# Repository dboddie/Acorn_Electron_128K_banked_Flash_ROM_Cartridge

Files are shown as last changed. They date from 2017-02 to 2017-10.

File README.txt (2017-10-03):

Introduction
------------

This repository provides schematic and circuit layout files for use with KiCad
describing a 128K Flash ROM cartridge suitable for use with the Acorn Electron
microcomputer's Plus 1 expansion unit. It is based on Paul Boddie's original
prototyping breakout cartridge.

The following resources are provided:

AcornElectronCartridge.kicad_pcb    The circuit board layout

AcornElectronCartridge.net          The netlist, generated from the schematic
                                    and distributed here for convenience

AcornElectronCartridge.pro          The KiCad project file

AcornElectronCartridge.sch          The circuit schematic providing the
                                    relationships between components

AcornElectron.lib                   Acorn Electron component library
                                    containing definitions for the edge
                                    connector (used by the schematic editor)

AcornElectron.pretty                Acorn Electron component footprint library
                                    containing definitions of the edge
                                    connector (used by the PCB editor)

BoardOutline                        Drawings defining the board outline plus
                                    descriptions of the drafting workflow and
                                    KiCad import considerations

Preparing the Schematic
-----------------------

Since the purpose of the board is merely that of routing signals, the
schematic is very simple. Connectors corresponding to the two sides of the
board edge connector are introduced, together with breakout connectors
corresponding to the exposed signals. Each edge connector pin is labelled and
a corresponding breakout connector pin is given a matching label. Thus, an
association is established between the edge connector pin and the breakout
pin.

The CvPcb tool in KiCad associates components with footprints. For convenient
prototyping, the breakout connectors are associated with headers with 0.1 inch
pin spacing (or pitch). The edge connectors are associated with specially
designed footprints for the Acorn Electron cartridge provided by the Acorn
Electron footprint component library (AcornElectron.pretty).

Preparing the Board Outline
---------------------------

In order to produce a board of the right shape (or indeed of any shape), a
board outline must first be produced. The BoardOutline directory contains
documentation of the workflow involved in applying measurements used by other
cartridges to produce a suitable drawing (cartridge_board_rear.dxf) which can
then be used in KiCad (and by subsequent production tools) to establish the
correct positions and dimensions of board features such as mounting holes and
the edge connector portion of the board.

This board outline is exported as DXF (using version 14 in Inkscape) and
imported into KiCad to provide the basis of the board itself. The outline is
imported into the Edge.Cuts layer, indicating that it shall be used to direct
cutting tools to define the shape of the board. In order to align the outline
with a grid using 0.127mm (0.05 inch) units, the origin of the outline is
positioned at (60.445mm, 127mm). More information about the calculations can
be found in the BoardOutline documentation.

Preparing the Board Layout
--------------------------

Each component must be positioned appropriately on the board for it to make
any physical sense. The edge connector footprints must be placed on each side
of the protruding portion of the board, and the breakout connector footprints
must be placed high enough up on the board to be accessible when the cartridge
is inserted into the Plus 1. Beyond this, board layout is mostly a matter of
routing tracks between connectors and avoiding board features such as mounting
holes and the board edges.

Design Rules and Production
---------------------------

The original prototyping cartridge was sent to OSHPark for production. Thus,
the design rules for OSHPark were added to the project configuration. Such
rules can be found here:

http://docs.oshpark.com/services/two-layer/
http://docs.oshpark.com/design-tools/kicad/kicad-design-rules/

Contact, Copyright and Licence Information
------------------------------------------

The author can be contacted at the following e-mail address:

david@boddie.org.uk

Copyright and licence information can be found in the docs directory - see
docs/COPYING.txt and docs/gpl-3.0.txt for more information.

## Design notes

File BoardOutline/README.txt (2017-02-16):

Files
-----

The cartridge_board_measurements.svg file was converted to the form defined by
cartridge_board.svg by removing dimension details, setting stroke widths to 0
for all objects, converting shapes to paths, performing a union operation on
the main board shape with the rectangles providing material for the edge
connector curvature (see below), then using the difference operation to remove
all cutout shapes. This should leave a single path object defining the board
minus the cutouts.

The cartridge_board_rear.svg file takes the board shape, flips it
horizontally, and converts all curves to lines by adding more points (three
times appears sufficient) and then using the curve-to-line operation. This
file is then exported to DXF (version 14) and produces the
cartridge_board_rear.dxf file.

Importing the cartridge_board_rear.dxf file into KiCad with the connectors
aligned to a 0.127mm grid, the offsets 60.445mm (3in - 15.755mm) and 127mm
(5in) can be used. The DXF file is suitable for designs where the rear of the
board is the focus, typically because that is the side on which components
will be mounted.

PCB Measurements
----------------

The cartridge_board_measurements.svg file summarises the details below.

ROM cartridge board width is 84.85mm, height is 62.5mm.

Mounting holes are at 4.975mm and 79.875mm horizontally with small holes
having a radius of 1.6mm and large holes having a radius of 3.75mm. Small
holes appear at 5.875mm and 45.875mm from the top of the board (56.625mm and
16.625mm from the bottom). Large holes appear at 36.875mm from the top of the
board (25.625mm from the bottom).

Two mounting slots of 2.2mm width are centred on 14.825mm and 70.025mm
horizontally. The front left (rear right) slot starts at 23.475mm from the top
of the board (39.025mm from the bottom) and ends at 35.575mm (26.925mm), then
being extended by a circular cutout of 1.1mm radius. The front right (rear
left) slot starts at the same vertical location but ends at 33.075mm
(29.425mm), being extended by the 1.1mm radius cutout. Thus, it is 2.5mm
shorter.

Edge Connector Pads
-------------------

Edge connector width is 56.5mm, height is 11.85mm.

The edge connector on the Advanced Computer Products cartridges (and
presumably the Acorn ones) curves into the lower edge of the main board area.
This curvature has a 1.1mm radius.

AppNote-014.pdf indicates that "Cartridges plug into a 44 way gold plated edge
connector arranged on each side of a 0.05 inch slot as 22 ways of 0.05" x 0.5"
on 0.1" centres."

Note that 2.54mm = 0.1in. Thus, "0.1" centres" indicates a spacing of 2.54mm.
The connectors are therefore 1.27mm x 12.7mm. The slot is 1.27mm (0.05in)
wide, presumably requiring such a board thickness.

  1.58mm margins from the edges to the centre of the first connector

  2.54mm between the centres of each connector

  22 connectors gives...

  (22 - 1) * 2.54mm + 2 * 1.58mm = 56.5mm

The edge connector has an offset of 14.175mm from the left edge of the board.

  (84.85mm - 56.5mm) / 2 = 14.175mm

The first connector has an offset of 15.755mm from the left edge of the board.

  14.175mm + 1.58mm = 15.755mm

The base of the connectors has an offset of 62.5mm from the top of the board,
being the base of the board.

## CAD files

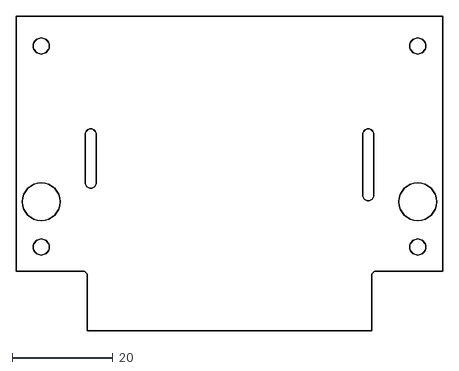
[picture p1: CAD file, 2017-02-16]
BoardOutline/cartridge_board_rear.dxf
84.9 x 62.5

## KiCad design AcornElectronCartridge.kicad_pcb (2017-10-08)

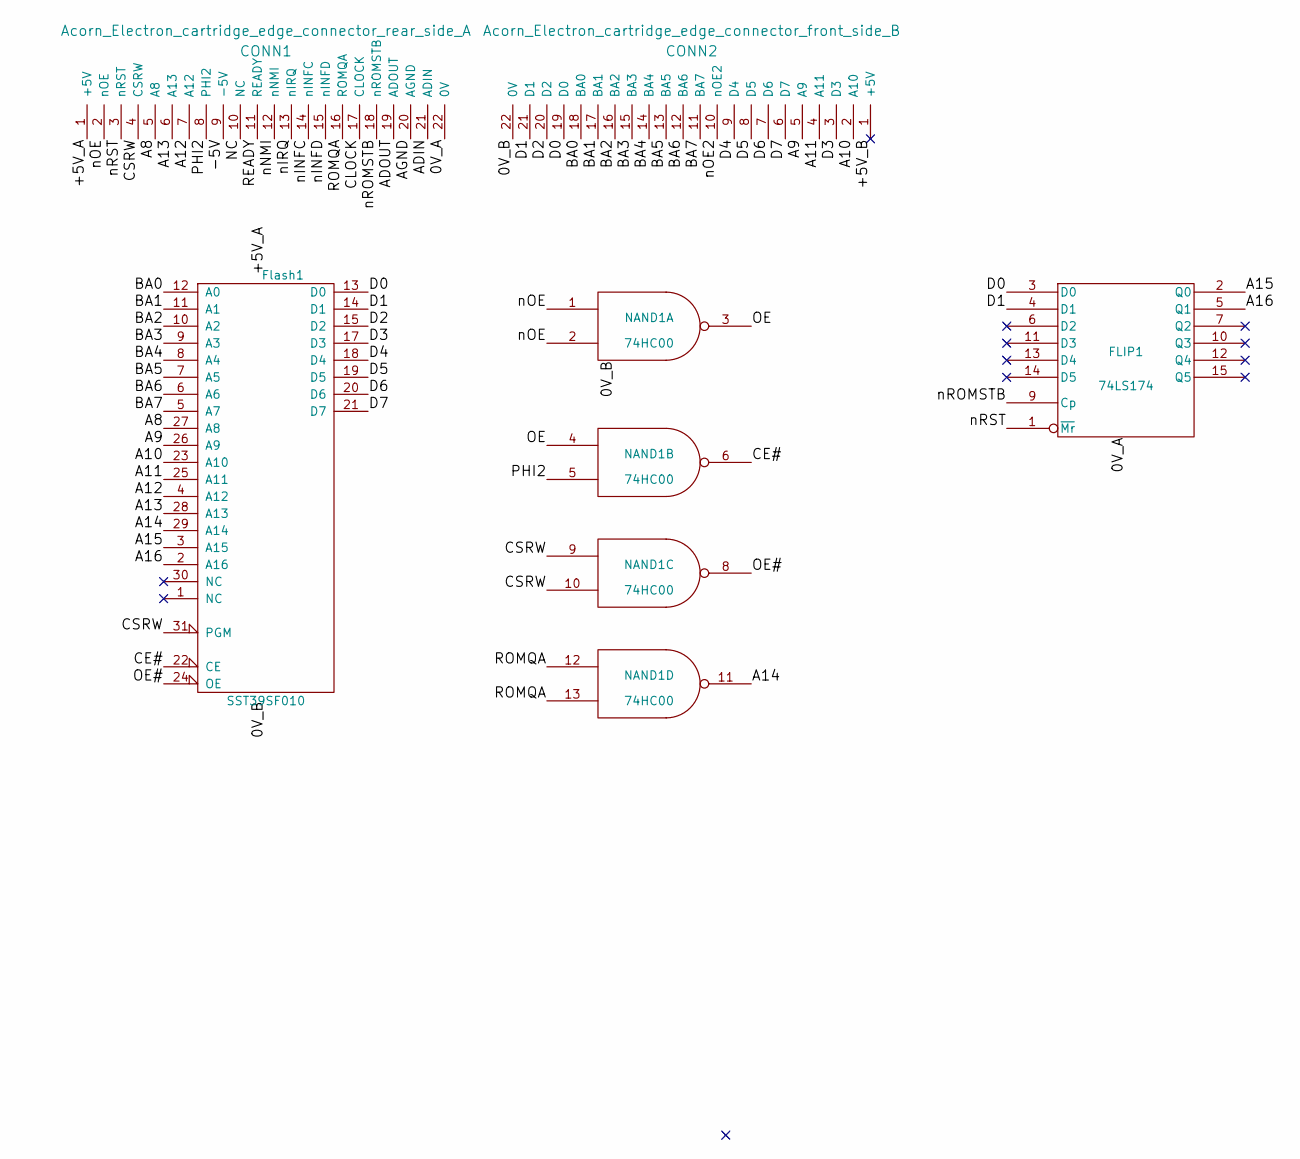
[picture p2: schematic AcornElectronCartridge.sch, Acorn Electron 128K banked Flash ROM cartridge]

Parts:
CONN1: Acorn_Electron_cartridge_edge_connector_rear_side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; Acorn_Electron_cartridge_edge_connector_rear
CONN2: Acorn_Electron_cartridge_edge_connector_front_sid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; Acorn_Electron_cartridge_edge_connector_front
FLIP1: 74LS174; DIP-16_W7.62mm_Socket
Flash1: SST39SF010; DIP-32_W15.24mm_Socket
NAND1: 74HC00; DIP-14_W7.62mm_Socket

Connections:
/+5V_B: CONN2.1 (+5V)
/-5V: CONN1.9 (-5V)
/A8: CONN1.5 (A8), Flash1.27 (A8)
/A9: CONN2.5 (A9), Flash1.26 (A9)
/A10: CONN2.2 (A10), Flash1.23 (A10)
/A11: CONN2.4 (A11), Flash1.25 (A11)
/A12: CONN1.7 (A12), Flash1.4 (A12)
/A13: CONN1.6 (A13), Flash1.28 (A13)
/A14: Flash1.29 (A14), NAND1.11
/A15: FLIP1.2 (Q0), Flash1.3 (A15)
/A16: FLIP1.5 (Q1), Flash1.2 (A16)
/ADIN: CONN1.21 (ADIN)
/ADOUT: CONN1.19 (ADOUT)
/AGND: CONN1.20 (AGND)
/BA0: CONN2.18 (BA0), Flash1.12 (A0)
/BA1: CONN2.17 (BA1), Flash1.11 (A1)
/BA2: CONN2.16 (BA2), Flash1.10 (A2)
/BA3: CONN2.15 (BA3), Flash1.9 (A3)
/BA4: CONN2.14 (BA4), Flash1.8 (A4)
/BA5: CONN2.13 (BA5), Flash1.7 (A5)
/BA6: CONN2.12 (BA6), Flash1.6 (A6)
/BA7: CONN2.11 (BA7), Flash1.5 (A7)
/CE#: Flash1.22 (CE), NAND1.6
/CLOCK: CONN1.17 (CLOCK)
/CSRW: CONN1.4 (CSRW), Flash1.31 (PGM), NAND1.9, NAND1.10
/D0: CONN2.19 (D0), FLIP1.3 (D0), Flash1.13 (D0)
/D1: CONN2.21 (D1), FLIP1.4 (D1), Flash1.14 (D1)
/D2: CONN2.20 (D2), Flash1.15 (D2)
/D3: CONN2.3 (D3), Flash1.17 (D3)
/D4: CONN2.9 (D4), Flash1.18 (D4)
/D5: CONN2.8 (D5), Flash1.19 (D5)
/D6: CONN2.7 (D6), Flash1.20 (D6)
/D7: CONN2.6 (D7), Flash1.21 (D7)
/NC: CONN1.10 (NC)
/OE: NAND1.3, NAND1.4
/OE#: Flash1.24 (OE), NAND1.8
/PHI2: CONN1.8 (PHI2), NAND1.5
/READY: CONN1.11 (READY)
/ROMQA: CONN1.16 (ROMQA), NAND1.12, NAND1.13
/nINFC: CONN1.14 (nINFC)
/nINFD: CONN1.15 (nINFD)
/nIRQ: CONN1.13 (nIRQ)
/nNMI: CONN1.12 (nNMI)
/nOE: CONN1.2 (nOE), NAND1.1, NAND1.2
/nOE2: CONN2.10 (nOE2)
/nROMSTB: CONN1.18 (nROMSTB), FLIP1.9 (Cp)
/nRST: CONN1.3 (nRST), FLIP1.1 (~Mr)
VCC: CONN1.1 (+5V), FLIP1.16 (VCC), Flash1.32 (VCC), NAND1.14 (VCC)

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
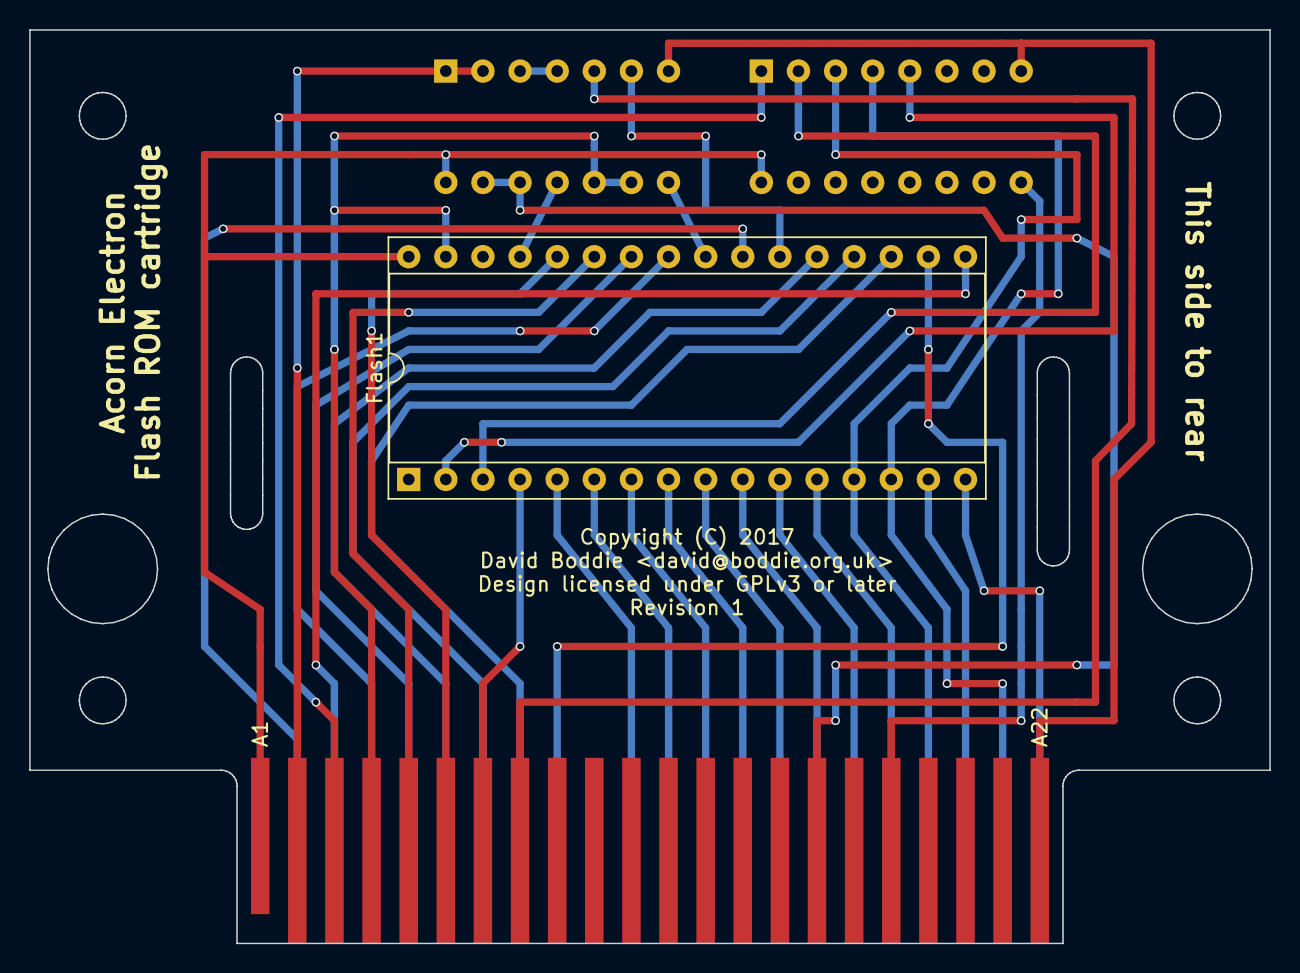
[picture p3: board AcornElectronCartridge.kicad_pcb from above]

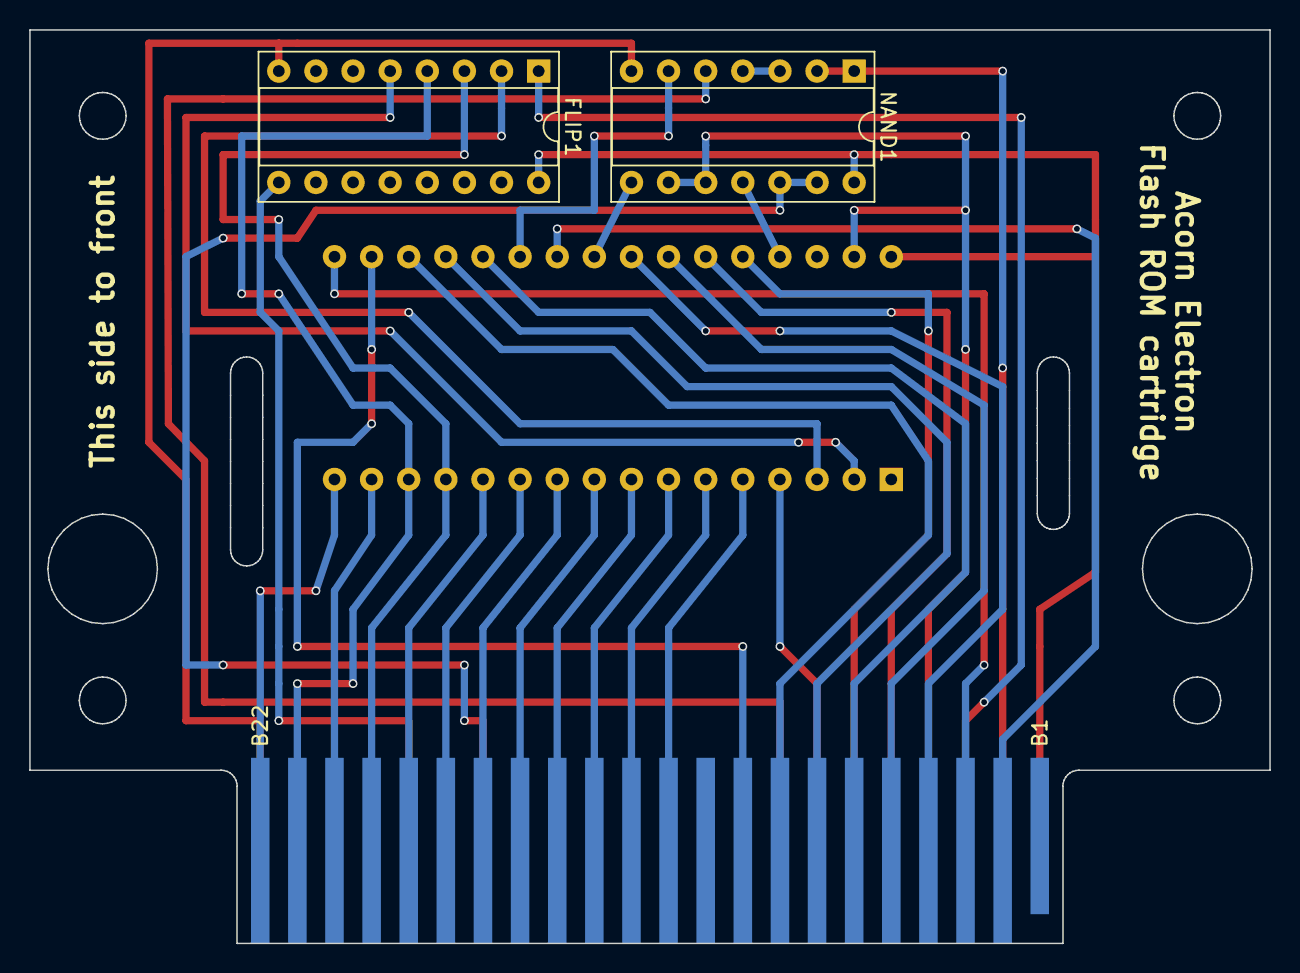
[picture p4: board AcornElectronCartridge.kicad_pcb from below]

Board: 2 copper layers, 84.9 x 62.5 mm, 5 parts (3 on the bottom side), 36 nets.

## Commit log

2017-01-18 An Acorn Electron prototyping/breakout cartridge.
    [AcornElectronCartridge-B.Cu.gbl, AcornElectronCartridge-B.Mask.gbs, AcornElectronCartridge-B.SilkS.gbo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]
2017-01-19 Introduced separate front and rear edge connector footprints. Moved various labels on the edge connector components and footprints, also changing the visible name labels to use spaces instead of unde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
    [AcornElectronCartridge-B.Cu.gbl, AcornElectronCartridge-B.Mask.gbs, AcornElectronCartridge-B.SilkS.gbo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]
2017-01-19 Changed the front edge connector to be associated with B.Cu rather than F.Cu (with which the rear edge connector is associated). None of the pad layers are changed.
    [AcornElectronCartridge-B.Cu.gbl, AcornElectronCartridge-B.Mask.gbs, AcornElectronCartridge-B.SilkS.gbo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]
2017-01-19 Adjusted "keep out" regions, moving some tracks closer to avoid these regions.
    [AcornElectronCartridge-B.Cu.gbl, AcornElectronCartridge-B.Mask.gbs, AcornElectronCartridge-B.SilkS.gbo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]
2017-02-16 Added project metadata to the schematic and board files.
    [AcornElectronCartridge.kicad_pcb, AcornElectronCartridge.sch]
2017-02-16 Added the component footprint library to the project itself for convenience.
2017-02-16 Added board outline details previously retained by the AcornElectron repository in its CartridgePCB subdirectory.
    [cartridge_board_rear.dxf]
2017-02-16 Updated the netlist. Various library settings and metadata were also updated.
    [AcornElectronCartridge.kicad_pcb]
2017-02-16 Tested Gerber output with only metadata changing.
    [AcornElectronCartridge-B.Cu.gbl, AcornElectronCartridge-B.Mask.gbs, AcornElectronCartridge-B.SilkS.gbo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]
2017-02-18 Fixed large hole width labels.
2017-10-02 Removed footprints, pads, vias and tracks. Changed labels to reflect the new use for the design.
    [AcornElectronCartridge.kicad_pcb]
2017-10-03 Finished the basic design.
    [AcornElectronCartridge.kicad_pcb, AcornElectronCartridge.sch]
2017-10-03 Renamed components. Tidied up a little.
    [AcornElectronCartridge.kicad_pcb, AcornElectronCartridge.sch]
2017-10-03 More minor improvements.
    [AcornElectronCartridge.kicad_pcb, AcornElectronCartridge.sch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]
2017-10-03 Updated the instructions to refer to the current design.
2017-10-03 Moved two tracks to the other side of the board for clarity.
    [AcornElectronCartridge.kicad_pcb]
2017-10-07 Removed the pads and added flip-flops to support the use of the FC73 paging register for software-enabled bank selection.
    [AcornElectronCartridge.kicad_pcb, AcornElectronCartridge.sch]
2017-10-07 Moved a via away from a silkscreen line.
    [AcornElectronCartridge.kicad_pcb]
2017-10-07 Removed an unused track.
    [AcornElectronCartridge.kicad_pcb]
2017-10-07 Tidied up tracks to leave more space between silkscreen markings and vias. Only used one +5V line and kept the 0V lines separate.
    [AcornElectronCartridge.kicad_pcb, AcornElectronCartridge.sch]
2017-10-08 Placed all tracks linked to flash ROM pads on the same side of the board.
    [AcornElectronCartridge.kicad_pcb, AcornElectronCartridge.sch]
2017-10-08 Left more room between pads and tracks.
    [AcornElectronCartridge.kicad_pcb]
2017-10-08 Moved a via away from silkscreen text.
    [AcornElectronCartridge.kicad_pcb]
2017-10-08 Tweaking a via position.
    [AcornElectronCartridge.kicad_pcb]

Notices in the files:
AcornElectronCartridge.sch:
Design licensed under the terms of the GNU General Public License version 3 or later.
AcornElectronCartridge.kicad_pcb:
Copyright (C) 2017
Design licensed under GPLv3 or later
